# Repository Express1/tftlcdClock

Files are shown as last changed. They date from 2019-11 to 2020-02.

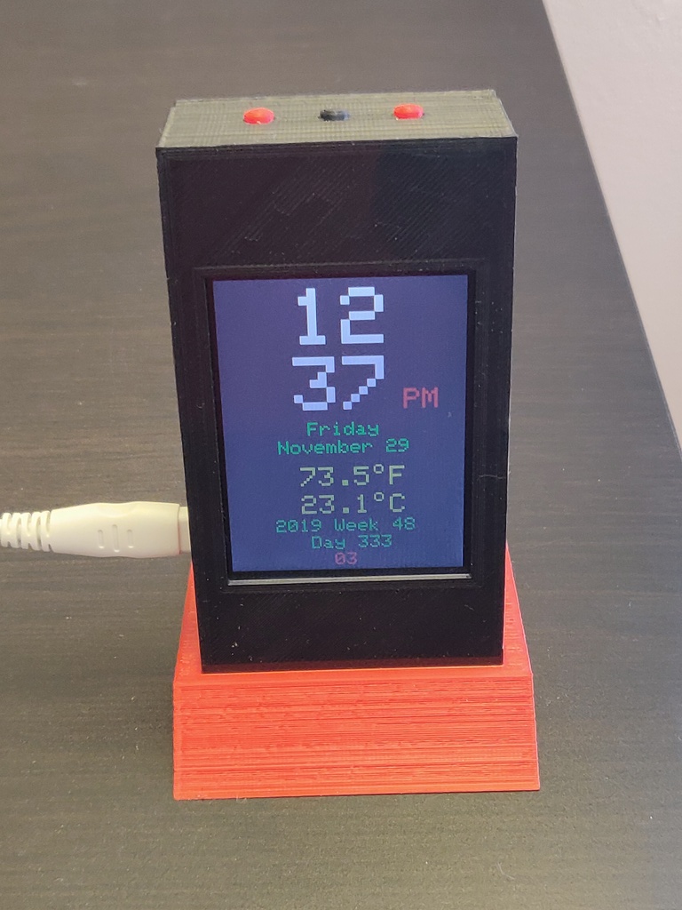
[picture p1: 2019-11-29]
pictures/IMG_20191129_123751-4.jpg

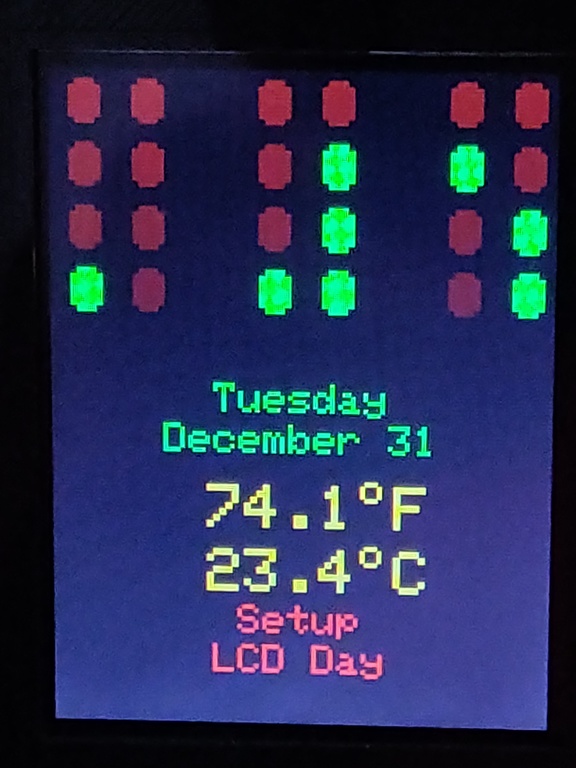
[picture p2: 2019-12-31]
pictures/IMG_20191231_102230.jpg

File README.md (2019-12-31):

TFT LCD Arduino Clock - Just another Arduino Clock...

This one is using a 320X240 ILI9341 tft lcd connected over SPI, the speed is acceptable for a clock display and will not use as many I/O pins as a parallel connected display.
Here is a link for the display:
https://www.aliexpress.com/item/32889801161.html?spm=a2g0s.9042311.0.0.29594c4dvsZfeP

The clock has a Digital display mode and a Binary BCD display mode selectabe from the menu.

Other modules used: DS3231 Clock module, remove the 1N4148 diode if you use that with a CR2032 battery, we do not want to charge the battery. DS18B20 temperature sensor module for better temp readings - there is a temperature sensor inside DS3231 also but the chip will heat up inside the clock case once powered on and will show about 1-2C more than the actual temp in few minutes.

The LCD I/O is 3v3 and therefore we use some resistors to convert from 5V to 3v3. There are 3 buttons for setup and a speaker for alarm. A piezo  or electromagnetic buzzer can be used.

The clock has an enclosure and a stand designed in OpenSCAD, make one using your 3DPrinter.

The menu of this clock is designed around a struct in PROGMEM in order to use less RAM, for those interested this can be reused as a menu for other projects. It was an interesting exercise to create and is working quite nice with the three buttons: "-", "Setup" and "+". Can be easily extended as necessary.

Menu:
Time hour, min (setting min will also reset seconds to 00), month, date, day of week, year.
Clock 12/24h, clock mode - digital or BCD binary.
Alarm hour, min, alarm days - daily or workdays only.
DST on week, month, DST off week, mo - For US DST set to 2,3 - 1,11. The week is the number of week in a mo starting Mo. The time will adjust on Su 2AM.
LCD day, night - lcd backlight durring day and night, will turn on on 7 and turn off at 10 pm.

All the libraries used are in a zip file (unzip under your libraries folder), the font file form Adafruit_GFX is modified “ char is replaced by a full circle character used by the BCD clock display and the second half of the table is removed in order to save space.

IOAbstraction lib is used to provide the low level functions for buttons and event scheduler, many thanks to Dave!
https://www.thecoderscorner.com/products/arduino-libraries/io-abstraction/ioabstraction-pins-io-expanders-shiftreg/

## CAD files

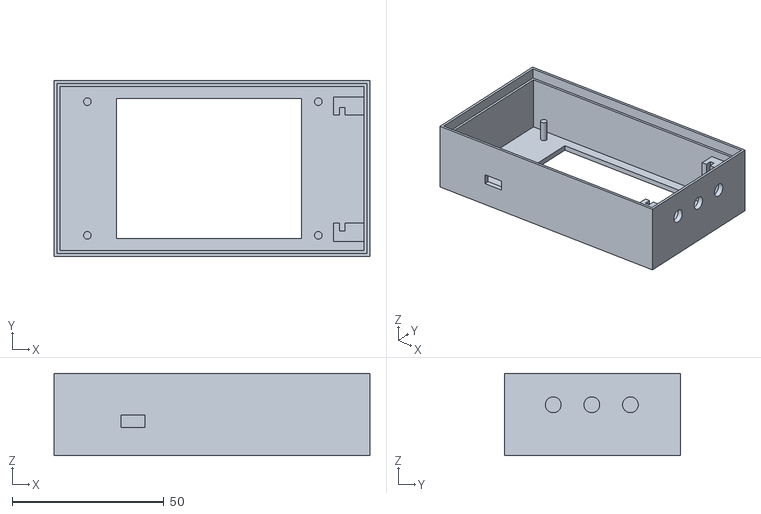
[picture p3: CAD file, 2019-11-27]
enclosure/boxLCD2p8.stl
104.0 x 58.0 x 27.0

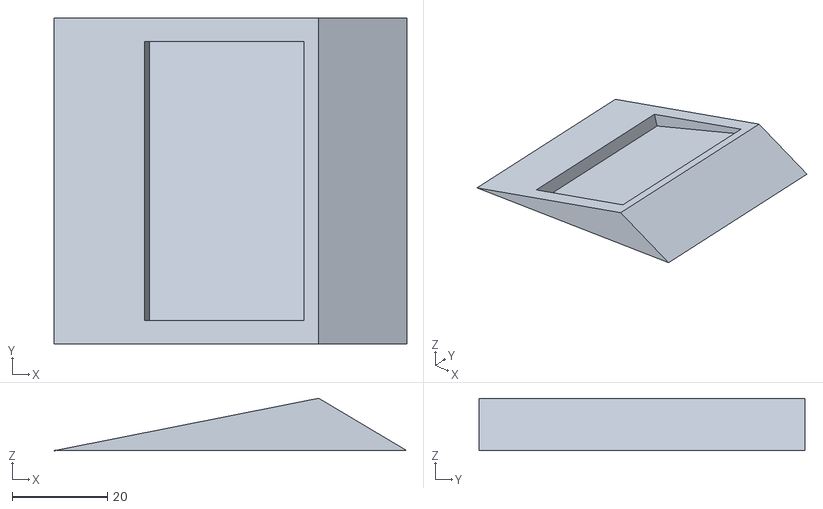
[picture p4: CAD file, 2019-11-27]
enclosure/box2p8support15.stl
74.0 x 68.4 x 11.0

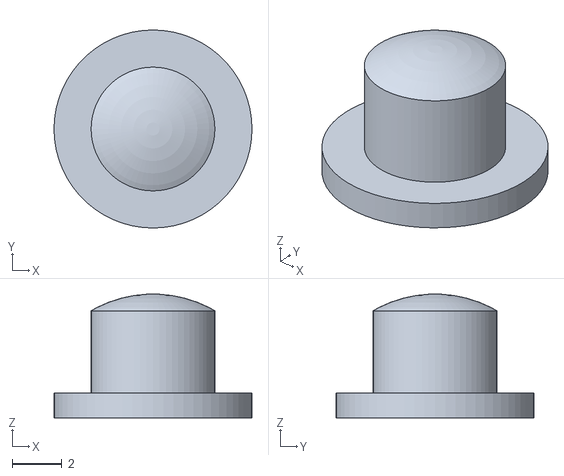
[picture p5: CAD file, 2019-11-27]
enclosure/button_clock.stl
8.00 x 8.00 x 4.99

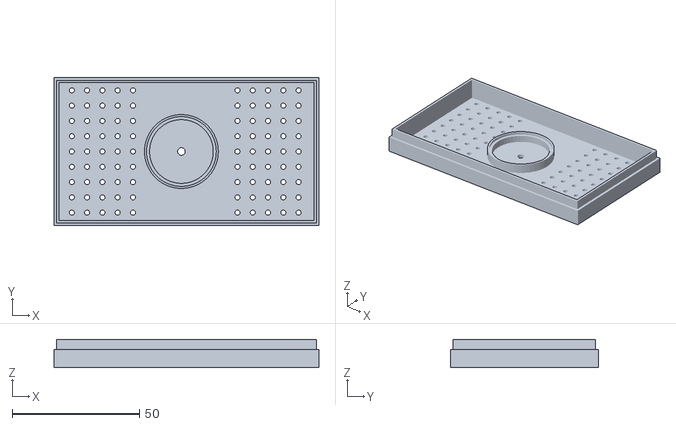
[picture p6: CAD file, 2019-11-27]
enclosure/backboxLCD2p8.stl
104.0 x 58.0 x 11.0

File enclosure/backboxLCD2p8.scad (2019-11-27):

// tftlcdClock back cover
$fn = $preview ? 12 : 72;

// inside size
wid1 = 54;
len1= 90+10;
height = 10;
wall = 2;
gap = 0.05;
cornerRadius = 10;

//buttons
 s=2.54;
 g=0.2;
 sy=11;  




//top

translate([0 , 0, 0]){
    mirror([0,0,0]) {
        //roundedBox(wid1, len1, 1, cornerRadius);
       difference() {
            roundedBox(wid1+2*wall, len1+2*wall, height/2+wall, cornerRadius);
            union() {
            translate([wall,wall,wall]) roundedBox(wid1, len1, height/2, cornerRadius);
            // holes 
            for (a2 =[0:4]) for (a1 =[1:9]) translate([wall+5+a2*6,a1*6-1,0]) cylinder(wall,d=2);
            for (a2 =[0:4]) for (a1 =[1:9]) translate([wall+70+a2*6,a1*6-1,0]) cylinder(wall,d=2);
            // buzzer    
            translate([50,29,0]) cylinder(wall,d=3);
            }
    }
    // 1 mm thick, 4 mm high
    // gap so we can close the box easy
    
    translate([wall-1,wall-1,height/2+wall]) {    
    difference() {
            roundedBox(wid1+2-gap,len1+2-gap,4,cornerRadius);
            translate([1,1,0]) {
                roundedBox(wid1,len1,4,cornerRadius);
            }    
        }
    }
  }

//buzzer

    difference() {
        translate([50,29,wall]) cylinder(r=27/2+1,h=4,center=false);
        union() {
            translate([50,29,wall])cylinder(r=27/2-1,h=4,center=false);
            translate([50,29,wall+3])cylinder(r=27/2+0.2,h=1,center=false);
            }    
        }

}



module roundedBox(wid1, len1, height, radius)
{
    dRadius = 2*radius;
    cube(size=[len1,wid1, height]);
  
}

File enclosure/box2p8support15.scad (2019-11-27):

//lcd 2.8 box top
$fn = $preview ? 12 : 72;
w=68.4;
l=74;
h=11;

difference() {
polyhedron( points = [ [0,0,0], [l,0,0], [l,w,0], [0,w,0], [l*3/4,0,h], [l*3/4,w,h]], faces =[[0,1,2,3], [0,4,1], [0,3,5,4], [4,5,2,1], [3,2,5] ], convexity = 2);

#translate([20, 5, 0]) rotate(a=[0,-15,0]) cube([34,58.4,10],false);
}

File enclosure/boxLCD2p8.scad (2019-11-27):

//lcd 2.8 box top
$fn = $preview ? 12 : 72;
//
// inside size
wid1 = 54;
len1= 90+10;
height = 50;
wall = 2;
gap = 0.05;
cornerRadius = 10;

//buttons
 s=2.54;
 g=0.2;
 sy=11;  


//bottom
difference() {
    translate([0, 0, 0]) roundedBox(wid1+2*wall, len1+2*wall, height/2+wall,cornerRadius);
    union() { 
        translate([wall,wall,wall]) roundedBox(wid1, len1, height/2, cornerRadius); 
        translate([wall-1,wall-1,height/2+wall-4-gap]) roundedBox(wid1+2,len1+2,4+gap,cornerRadius);
        //lcd hole
        translate([17+2+wall-0.5,4+wall,0]) cube(size=[61,46,wall]);
        //cuts for buttons    
        translate([len1+wall,sy,wall]) 
            union()
                for (a =[0:2])  
                {
                 #translate([0,0+a*s*5+2*s,wall+12.7]) rotate([0,90,0]) cylinder(d=5.2,h=wall);
                 *translate([0,0+a*s*5,0]) cube(size=[wall,g,6*s]); 
                 *translate([0,4*s+a*s*5,0]) cube(size=[wall,g,6*s]);
                 *translate([0,+a*s*5,6*s]) cube(size=[wall,4*s+g,g]);  
                }
         //buzzer hole
         *translate ([50,wall,23]) rotate(a=[90,0,0]) cylinder(r=1.5,h=2,center=false);  
         // USB hole
         #translate ([18+2+wall,wall,7.3+wall]) rotate(a=[90,0,0]) cube(size=[8,4,wall]);      
        }
    } 



//LCD feet
 translate([9+wall,5+wall,wall]) {
    cylinder(8,d=2.5);
        }
translate([85+wall,5+wall,wall]) {
    cylinder(8,d=2.5);
        }
        translate([9+wall,49+wall,wall]) {
    cylinder(8,d=2.5);
        }
        translate([85+wall,49+wall,wall]) {
    cylinder(8,d=2.5);
        }

// button rails
     
    difference() {
    translate([wall+len1-10,sy-6,wall]) cube(size=[10,6,8*s]);
    translate([wall+len1-10+2,sy-s,wall]) cube(size=[1.8,s,8*s]);
                 }    
         
    difference() {
    translate([wall+len1-10,sy+3*5*s-s,wall]) cube(size=[10,6,8*s]);
    translate([wall+len1-10+2,sy+3*5*s-s,wall]) cube(size=[1.8,s,8*s]);
    }


//buzzer
    *translate ([50,4,23])
    rotate(a=[90,0,0]) {
    difference() {
        cylinder(r=27/2+1,h=2,center=false);
        union() {
            cylinder(r=27/2,h=2,center=false);
            cylinder(r=27/2+0.1,h=0.5,center=false);
            } 
    }
}  




module roundedBox(wid1, len1, height, radius)
{
    dRadius = 2*radius;
    cube(size=[len1,wid1, height]);
  
}

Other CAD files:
enclosure/button_clock.scad

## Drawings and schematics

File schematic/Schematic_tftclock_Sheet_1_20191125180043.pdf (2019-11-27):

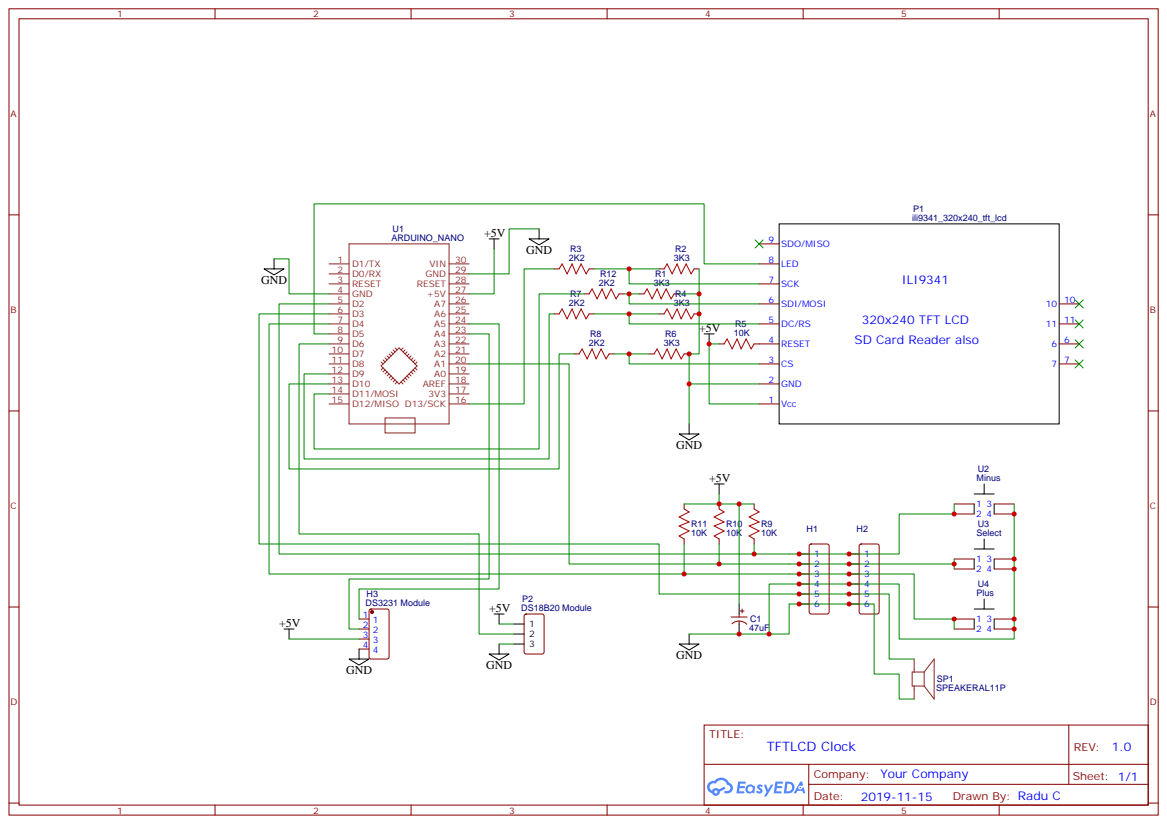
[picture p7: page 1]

320x240 TFT LCD
SD Card Reader also

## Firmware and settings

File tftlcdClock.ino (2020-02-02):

/*
   tft lcd Clock Arduino Clock

   Copyright 2019 Radu Constantinescu
   https://github.com/Express1/tftlcdClock

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
   You should have received a copy of the GNU General Public License
   along with this program; if not, write to the Free Software
   Foundation, Inc., 51 Franklin Street, Fifth Floor, Boston,
   MA 02110-1301, USA.
*/

//11/1/2020 fix DOW and DST

//Libraries
//#include <avr/pgmspace.h>
#include<IoAbstraction.h>
#include <EepromAbstraction.h>
#include <ArduinoEEPROMAbstraction.h>

#include "Adafruit_GFX.h"
#include "Adafruit_ILI9341.h"
#include <Wire.h>
#include "Sodaq_DS3231.h"
#include  <SPI.h>

//DS18B20 temp sensor
#include <OneWire.h>
#include <DS18B20.h>

#define ONE_WIRE_BUS 6

OneWire oneWire(ONE_WIRE_BUS);
DS18B20 sensor(&oneWire);
//

#define TFT_DC 9
#define TFT_CS 10
#define TFT_RST 8
#define TFT_MISO 12
#define TFT_MOSI 11
#define TFT_CLK 13

#define PINTFTLED 5
#define PINSPK 3

// used to change the LCD backlight, military time
#define STARTDAY 7
#define STARTNIGHT 22

// buttons
const int menubutton = A1;
const int minusbutton = 2;
const int plusbutton = 4;

//print info to serial
#define debug_s

char buffer[32];  //buffer
char ast[10];  //a string
uint8_t seconds; // seconds from timer chip
uint8_t minutes, hours, hours1; // last min value

uint8_t alarmon, alarmcount; //used durring alarm

uint8_t mode; // 0 = clock, 1 = BCD, 2 = setup
uint8_t menui; //menuitem

AvrEeprom anEeprom;
DateTime now;


//Adafruit_ILI9341 tft = Adafruit_ILI9341(TFT_CS, TFT_DC, TFT_MOSI, TFT_CLK, TFT_RST, TFT_MISO);
//https://forum.developer.sony.com/topic/59/hardware-spi-not-working-for-ili9340-9341-tft-display-sw-spi-does/5
// Use hardware SPI (on Uno, #13, #12, #11) and the above for CS/DC
Adafruit_ILI9341 tft = Adafruit_ILI9341(TFT_CS, TFT_DC); //HARDWARE SPI, fast
//Adafruit_ILI9341 tft = Adafruit_ILI9341(10, 9, 11, 13, 8); //SOFTWARE SPI, slow


// we define all the strings in PROGMEM

// max# of char in the array+1
const int CHARCOUNT = 10;

/*Su=1 Mo=2 Tu=3 We=4 Th=5 Fr=6 Sa=7 */
const char dayofweek [7] [CHARCOUNT] PROGMEM = {
  { "Sunday" },
  { "Monday" },
  { "Tuesday" },
  { "Wednesday" },
  { "Thursday" },
  { "Friday" },
  { "Saturday" },
};

const char months [12] [CHARCOUNT] PROGMEM = {
  { "January" },
  { "February" },
  { "March" },
  { "April" },
  { "May" },
  { "June" },
  { "July" },
  { "August" },
  { "September" },
  { "October" },
  { "November" },
  { "December" }
};

const char h1224 [2] [CHARCOUNT] PROGMEM = {
  { "24 hour" },
  { "12 hour" }
};

const char clmode [2] [CHARCOUNT] PROGMEM = {
  { "Digi Clk" },
  { "BCD Clk" }
};

const char cls[15] PROGMEM = "              ";
const char alm[5 + 1] PROGMEM = "ALARM";

const char apm [2] [2 + 1] PROGMEM = {
  { "AM" },
  { "PM" }
};

const char wday [2] [6 + 1] PROGMEM = {
  { " Week " },
  { " Day " }
};

const char alarmdays1 [3] [CHARCOUNT] PROGMEM = {
  { "AlarmOff" },
  { "Alarm On" },
  { "Workdays" }
};
const int MENUCOUNT = 18;
uint8_t menuval[MENUCOUNT];   // values for menu items

// menu callback routines

// set time
void settime1 (void) {
  DateTime now = rtc.now(); // keep seconds
  //int year = menuval[5] + 2000;
  //Serial.print(F("YYY"));
  //Serial.println(year);
  DateTime dt((menuval[5] + 2000), menuval[2], menuval[3], menuval[0], menuval[1], now.second(), menuval[4]);
  // Year, Month, Day, Hour, Minutes, Seconds, Day of Week
  rtc.setDateTime(dt); //Adjust date-time as defined 'dt' above
  mode = 3; //go back to setup
  //Serial.println (F("Routine 1"));
}

void settimemin (void) {
  DateTime now = rtc.now(); // reset seconds 
  DateTime dt((menuval[5] + 2000), menuval[2], menuval[3], menuval[0], menuval[1], 0, menuval[4]);
  // Year, Month, Day, Hour, Minutes, Seconds, Day of Week
  rtc.setDateTime(dt); //Adjust date-time as defined 'dt' above
  mode = 3; //go back to setup
}



void exitmenu2 (void) {
  mode = 3; //go back to setup
  // write an array to the rom.
  //anEeprom.writeArrayToRom(0, (const unsigned char*)menuval, sizeof menuval);
  //Serial.println (F("Routine 2"));
}

void setexit3 (void) {
  tft.fillRect(0, 0, 240, 140, ILI9341_BLACK);
  clearrow(260, 2);
  clearrow(280, 2);
  seconds--;
  minutes--; // force update sec,min, hour
  hours--;
  mode = menuval[7]; // exit menu, go back to clock
  // write an array to the rom.
  anEeprom.writeArrayToRom(0, (const unsigned char*)menuval, sizeof menuval);
  myclock();
  //Serial.println (F("Routine 3"));
}

void setlcd (void) {
  analogWrite(PINTFTLED, menuval[15]);
  mode = 3; //go back to setup
}

void setlcdn (void) {
  analogWrite(PINTFTLED, menuval[16]);
  mode = 3; //go back to setup
}
// if you want to understand how this does work read
// https://arduino.stackexchange.com/questions/13545/using-progmem-to-store-array-of-structs

struct MenuRecord
{
  uint8_t start;  // start at 0 or 1 or
  uint8_t count;  // how many, last is start+count-1
  char item[12 + 1]; // menu choice text to display
  char (*values)[CHARCOUNT];
  void (*set)();  // setup routine, call if we press set for an item
};

const MenuRecord menu[MENUCOUNT] PROGMEM = {
  { 0, 23, "Time hour", NULL , settime1 }
  , { 0, 59, "Time min", NULL , settimemin }
  , { 1, 12, "Month", months , settime1 }
  , { 1, 31, "Date", NULL, settime1 }
  , { 1, 7, "Day of week", dayofweek, settime1 }
  , { 19, 199, "Year", NULL, settime1 }
  , { 0, 1, "Clock 12/24H", h1224, setexit3 }
  , { 0, 1, "Clock mode", clmode, setexit3 }
  , { 0, 23, "Alarm hour", NULL, exitmenu2 }
  , { 0, 59, "Alarm min", NULL, exitmenu2 }
  , { 0, 2, "Alarm Days", alarmdays1 , exitmenu2 }
  , { 0, 5, "DSTonWeek", NULL , exitmenu2 }
  , { 0, 12, "DSTonMo", NULL , exitmenu2 }
  , { 0, 5, "DSToffWeek", NULL , exitmenu2 }
  , { 0, 12, "DSToffMo", NULL , exitmenu2 }
  , { 10, 255, "LCD Day", NULL , setlcd }
  , { 10, 255, "LCD Night", NULL , setlcdn }
  , { 0, 1, "Exit Setup", NULL, setexit3 }
};


/*
  menuval[0] hour 0-23
  menuval[1] min 0 -59
  menuval[2] month 1-12
  menuval[3] dayofmonth 1-31
  menuval[4] dayofweek 1-7, 1=Monday
  menuval[5] year last 2 digits 19XX
  menuval[6] 0=24h, 1=12h
  menuval[7] 0=digi, 1=bcd
  menuval[8] alarm hour
  menuval[9] alarm min
  menuval[10] alarm days 0=off, 1=on, 2=workdays
  menuval[11] DST on Week
  menuval[12] DST on Mo
  menuval[13] DST off Week
  menuval[14] DST off Mo
  menuval[15] LCD Light Day
  menuval[16] LCD Light Night
*/


void clearrow(int y, int textsize)
{
  //strcpy(buffer, "                ");
  memcpy_P (&buffer, &cls, 15);
  tftcprint(ILI9341_RED, y, textsize);
}

void onmenubutton(uint8_t pin, bool heldDown) {
  if (alarmon == 1) { //alarm stop
    alarmon = 0;
    noTone(PINSPK);
    // clear screen, print year info
    memcpy_P (&buffer, &alm, 6);
    tftcprint(ILI9341_BLACK, 260, 4);
    pyear();
  }
  else
  {
    if (!heldDown) {
      MenuRecord thisItem;
      switch (mode) {
        case 0 :
        case 1 :
          {
            mode = 3;  //setup mode
            menui = 0;
            clearrow(260, 2);
            strcpy(buffer, "Setup");
            tftcprint(ILI9341_RED, 260, 2);
            clearrow(280, 2);
            clearrow(300, 2);
            PROGMEM_readAnything (&menu [menui], thisItem);
            strcpy(buffer, thisItem.item);
            tftcprint(ILI9341_RED, 280, 2);
          }
          break;
        case 3 :
          { //show value to change
            if (menui == MENUCOUNT - 1) { //exit menu selection
              setexit3();
            }
            else {
              PROGMEM_readAnything (&menu [menui], thisItem);
              mode = 4; // the menu is selected to change values
              // show value on screen
              if (thisItem.values == NULL) {
                itoa (menuval[menui], buffer, 10);
              }
              else {
                //read day of week from menu record *
                memcpy_P (&buffer, &thisItem.values[menuval[menui] - thisItem.start], CHARCOUNT);
              }
              tftcprint(ILI9341_RED, 300, 2);
            }
          }
          break;
        case 4 :
          { //write value and go back to menu
            PROGMEM_readAnything (&menu [menui], thisItem);
            // now write the values and go back to mode 3
            thisItem.set();
            //mode = 3;
            //fix screen, delete line @ 300
            clearrow(300, 2);
            //tftcprint(ILI9341_RED, 300, 2);
          }
          break;
      }
    }
    //Serial.print(F("Button menu "));
    //Serial.println(heldDown ? F("Held") : F("Pressed"));
    //Serial.println(mode);
  }
}


// pin values
//const int minusbutton = 2;
//const int plusbutton = 4;
void onminusbutton(uint8_t pin, bool heldDown) {
  MenuRecord thisItem;
  PROGMEM_readAnything (&menu [menui], thisItem);

  switch (mode) {
    case 3 :
      {
        if (pin == minusbutton) {
          menui--;
          if (menui == 255) menui = MENUCOUNT - 1;
        }
        if (pin == plusbutton) {
          menui++;
          if (menui == MENUCOUNT) menui = 0;
        }

        clearrow(280, 2);
        PROGMEM_readAnything (&menu [menui], thisItem);
        strcpy(buffer, thisItem.item);
        tftcprint(ILI9341_RED, 280, 2);
      }
      break;
    case 4 :
      {
        if (pin == minusbutton) {
          if (menuval[menui] == thisItem.start)
          {
            menuval[menui] = thisItem.count;
          }
          else
          {
            menuval[menui]--;
          }
        }

        if (pin == plusbutton) {
          if (menuval[menui] == thisItem.count)
          {
            menuval[menui] = thisItem.start;
          }
          else
          {
            menuval[menui]++;
          }
        }

        clearrow(300, 2);
        if (thisItem.values == NULL) {
          itoa (menuval[menui], buffer, 10);
        }
        else {
          //read day of week from menu record *
          memcpy_P (&buffer, &thisItem.values[menuval[menui] - thisItem.start], CHARCOUNT);
        }
        tftcprint(ILI9341_RED, 300, 2);
      }
      break;
  }

  //Serial.println(pin);
  //Serial.println(menui);
  //Serial.print(F("Button minus "));
  //Serial.println(heldDown ? F("Held") : F("Pressed"));
}




void setup ()
{
  Wire.begin();
  rtc.begin();

  //DS18B20 tempp sensor
  sensor.begin();
  sensor.requestTemperatures();

  tft.begin();
  tft.setRotation(0);
  tft.fillScreen(ILI9341_BLACK);

  //lcd backlight
  pinMode(PINTFTLED, OUTPUT);
  

  //speaker
  pinMode(PINSPK, OUTPUT);
  tone(PINSPK, 1000, 100);

#ifdef debug_s
  Serial.begin (115200);
  Serial.println (F(">"));
#endif
  // read settings from EEPROM
  anEeprom.readIntoMemArray((const unsigned char*)menuval + 6, 0 + 6, sizeof menuval - 6); //skip rtc values 0-5

  // fix the values we read if the eeprom is empty
  for (int i = 0; i < sizeof menuval; i++) {
    //Serial.println (menuval[i]);
    if (menuval[i] == 255) menuval[i] = 0; // if we did read 255 from eeprom zero the parameter.
  }
  // fix Month and date if eeprom was empty, first start
  if (menuval[2] == 0) menuval[2] = 1; // Month Jan
  if (menuval[3] == 0) menuval[3] = 1; // Date 1

  // LCD Backlight
  if (menuval[15] < 10) menuval[15] = 10;  //otherwise we cannot see the display
  if (menuval[16] < 10) menuval[16] = 10;  
  analogWrite(PINTFTLED, menuval[15]);  // we start the clock durring day
  
  //setRTCTime();
  
  // read RTC values from clock chip
  now = rtc.now();
  menuval[0] = now.hour();
  menuval[1] = now.minute();
  menuval[2] = now.month();
  menuval[3] = now.date();
  menuval[4] = now.dayOfWeek();
  menuval[5] = uint8_t(now.year() - 2000);

  // hours, AM/PM correction
  hours1 = menuval[0];
  if (hours1 > 12) hours1 = hours1 - menuval[6] * 12;
  if (hours1 < 1) hours1 = hours1 + menuval[6] * 12;

  mode = menuval[7];  //set mode 0 = digi, 1 = bcd

  /*
    for (int i = 0; i < 12; i++)
    {
      // make a copy of the current one
      memcpy_P (&buffer, &months[i], CHARCOUNT);
      Serial.println (buffer);
    } // end of for loop

    memcpy_P (&buffer, &months[2], CHARCOUNT);
    for (int i = 0; i < 32; i++)
    {
      byte x = buffer[i];
      Serial.print(x);
      Serial.print(F(" "));
    }

    // string concat with int example
    int aaa = 30;
    char ast[10];
    itoa (aaa, ast, 10);
    strcat(buffer, " ");
    strcat(buffer, ast);
    Serial.println(F(""));
    Serial.println (buffer);
    Serial.println (strlen(buffer));

    // Menu array in PROGMEM
    MenuRecord thisItem;
    PROGMEM_readAnything (&menu [4], thisItem);
    Serial.println (thisItem.item);
    Serial.println (thisItem.count);
    //thisItem.set();
    //read day of week from menu record *
    memcpy_P (&buffer, &thisItem.values[4], CHARCOUNT);
    Serial.println (buffer);
  */

  //iobuttons
  // First we set up the switches library, giving it the task manager and tell it to use arduino pins
  // We could also of chosen IO through an i2c device that supports interrupts.
  // If you want to use PULL DOWN instead of PULL UP logic, change the true to false below.
  // true = button connected to ground
  switches.initialise(ioUsingArduino(), true);

  // now we add the switches, we dont want the spinwheel button to repeat, so leave off the last parameter
  // which is the repeat interval (millis / 20 basically) Repeat button does repeat as we can see.
  //switches.addSwitch(spinwheelClickPin, onSpinwheelClicked);
  //switches.addSwitch(repeatButtonPin, onRepeatButtonClicked, 25);

  switches.addSwitch(menubutton, onmenubutton);
  switches.addSwitch(minusbutton, onminusbutton, 25);
  switches.addSwitch(plusbutton, onminusbutton, 25);


  // run the clock display
  taskManager.scheduleFixedRate(990, myclock);  //once per second+sync

}

// end of setup

void loop () {
  taskManager.runLoop();
}

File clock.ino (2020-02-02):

/*
  // Color definitions
  #define ILI9341_BLACK       0x0000  ///<   0,   0,   0
  #define ILI9341_NAVY        0x000F  ///<   0,   0, 123
  #define ILI9341_DARKGREEN   0x03E0  ///<   0, 125,   0
  #define ILI9341_DARKCYAN    0x03EF  ///<   0, 125, 123
  #define ILI9341_MAROON      0x7800  ///< 123,   0,   0
  #define ILI9341_PURPLE      0x780F  ///< 123,   0, 123
  #define ILI9341_OLIVE       0x7BE0  ///< 123, 125,   0
  #define ILI9341_LIGHTGREY   0xC618  ///< 198, 195, 198
  #define ILI9341_DARKGREY    0x7BEF  ///< 123, 125, 123
  #define ILI9341_BLUE        0x001F  ///<   0,   0, 255
  #define ILI9341_GREEN       0x07E0  ///<   0, 255,   0
  #define ILI9341_CYAN        0x07FF  ///<   0, 255, 255
  #define ILI9341_RED         0xF800  ///< 255,   0,   0
  #define ILI9341_MAGENTA     0xF81F  ///< 255,   0, 255
  #define ILI9341_YELLOW      0xFFE0  ///< 255, 255,   0
  #define ILI9341_WHITE       0xFFFF  ///< 255, 255, 255
  #define ILI9341_ORANGE      0xFD20  ///< 255, 165,   0
  #define ILI9341_GREENYELLOW 0xAFE5  ///< 173, 255,  41
  #define ILI9341_PINK        0xFC18  ///< 255, 130, 198
*/

/*
  void setRTCTime()
  {
  DateTime dt(2019, 11, 11, 17, 21, 00, 0); // Year, Month, Day, Hour, Minutes, Seconds, Day of Week
  rtc.setDateTime(dt); //Adjust date-time as defined 'dt' above
  }
*/

void tftcprint(uint16_t color, int y, int textSize)
// print buffer[] center justified on tft
{
  int x;
  //chard are 5X7 with one px space, 6 px width.
  x = (240 - strlen(buffer) * 6 * textSize) / 2;
  //if (x < 0) {
  //  x = 0;
  //};
  /*
    Serial.print (F("center x:"));
    Serial.print (x);
    Serial.print (F(" strlen:"));
    Serial.println (strlen(buffer));
      for (int i = 0; i < 16; i++)
    {
      byte x = buffer[i];
      Serial.print((buffer[i]));
      Serial.print(x);
      Serial.print(F(" "));

    }
    Serial.println("");
  */
  tftprint(color, x, y, textSize);
}


void tftprint(uint16_t color, int x, int y, int textSize)
// print buffer[] on tft, will delete previous text
// https://github.com/adafruit/Adafruit-GFX-Library/issues/16 , have print clear existing text
//To prevent having to clear the text before its drawn,
//like AKA mentions try using the bg color by calling setTextColor(foreground color, background color)
{
  //Serial.println (buffer);
  tft.setCursor(x, y);
  tft.setTextColor(color, ILI9341_BLACK);
  tft.setTextSize(textSize);
  tft.setTextWrap(true);
  tft.print(buffer);

}


void ptemp()
{

  // RTC temp sensor
  rtc.convertTemperature();
  float temperaturec = rtc.getTemperature();
  Serial.print(sensor.getTempC());
  Serial.print(F(" "));
  //

  // DS18B20 temp sensor
  //float
  temperaturec = sensor.getTempC() - 0.5;
  //Serial.println(sensor.getTempC());
  sensor.requestTemperatures();

  //

  float temperaturef;
  temperaturef = (temperaturec * 1.8) + 32;

  dtostrf(temperaturef, 5, 1, buffer);
  strcat(buffer, " F");
  tftcprint(ILI9341_YELLOW, 200, 3);
  strcpy(buffer, "o");
  tftprint(ILI9341_YELLOW, 149, 194, 2);

  dtostrf(temperaturec, 5, 1, buffer);
  strcat(buffer, " C");
  tftcprint(ILI9341_YELLOW, 200 + 8 * 4, 3);
  strcpy(buffer, "o");
  tftprint(ILI9341_YELLOW, 149, 194 + 8 * 4, 2);

#ifdef debug_s
  Serial.print(temperaturec); //read registers and display the temperature
  Serial.print(F(" C / "));
  Serial.print(temperaturef); //read registers and display the temperature
  Serial.println(F(" F"));
#endif
}

// BCD display parameters
#define S 3 //char size 20/2 or 30/3
#define P 30 //spacing

#define C ILI9341_GREEN //color on
#define O ILI9341_MAROON //color off

#define X 10 //X offset
#define Y 5 //Y offset

void bcdp(uint8_t val, uint8_t x )
{
  for (int i = 0; i < 4; i++) {
    if (val & (0b1000 >> i)) {
      strcpy(buffer, "\""); tftprint(C, x * P + X, P * i + Y, S);
    }
    else {
      strcpy(buffer, "\""); tftprint(O, x * P + X, P * i + Y, S);
    }
  }
}


void pyear()
//DayWeekNumber: Calculate day of year and week of year
// this routine does come from http://arduino.joergeli.de
/*
  menuval[0] hour 0-23
  menuval[1] min 0 -59
  menuval[2] month 1-12
  menuval[3] dayofmonth 1-31
  menuval[4] dayofweek 0-6, 0=Monday
  menuval[5] year last 2 digits 19XX
*/
{
  int days[] = {0, 31, 59, 90, 120, 151, 181, 212, 243, 273, 304, 334};
  int DN, WN;
  // Number of days at the beginning of the month in a not leap year.
  //Start to calculate the number of day
  if (menuval[2] == 1 || menuval[2] == 2) {
    DN = days[(menuval[2] - 1)] + menuval[3]; //for any type of year, it calculate the number of days for January or february
  }                                                          // Now, try to calculate for the other months
  else if (((menuval[5] + 2000) % 4 == 0 && (menuval[5] + 2000) % 100 != 0) ||  (menuval[5] + 2000) % 400 == 0) { //those are the conditions to have a leap year
    DN = days[(menuval[2] - 1)] + menuval[3] + 1;                              // if leap year, calculate in the same way but increasing one day
  }
  else {                                                     //if not a leap year, calculate in the normal way, such as January or Febr
    DN = days[(menuval[2] - 1)] + menuval[3];
  }
  // Now start to calculate Week number
  if (menuval[4] == 0) {
    WN = (DN - 7 + 10) / 7;                                  //if it is sunday (time library returns 0)
  }
  else {
    WN = (DN - menuval[4] + 10) / 7;                                  // for the other days of week
  }

  itoa ((menuval[5] + 2000), buffer, 10);
  memcpy_P (&ast, wday[0], 7);
  strcat(buffer, ast);
  itoa (WN, ast, 10);
  strcat(buffer, ast);
  tftcprint(ILI9341_GREEN, 260, 2);
  memcpy_P (&buffer, wday[1], 7);
  //strcpy(buffer, " Day ");
  itoa (DN, ast, 10);
  strcat(buffer, ast);
  tftcprint(ILI9341_GREEN, 280, 2);
}


void doalarm()
{
  // if (alarmon == 0) {
  alarmon = 1;
  alarmcount = 60;
  //memcpy_P (&buffer, &alm, 6);
  //tftcprint(ILI9341_RED, 260, 4);
  doalarm1();
  // }
#ifdef debug_s
  Serial.println (F("Alarm"));
#endif

}

void doalarm1()
{
  if (alarmon == 1 && alarmcount > 0) {
    taskManager.scheduleOnce(1000, doalarm1);
    tone(PINSPK, 1000, 600);

    memcpy_P (&buffer, &alm, 6);
    if (alarmcount % 2 == 0) {
      tftcprint(ILI9341_RED, 260, 5);
    }
    else {
      tftcprint(ILI9341_BLACK, 260, 5);
    }

    alarmcount--;
#ifdef debug_s
    //Serial.println(alarmcount);
    //Serial.println(millis());
#endif
  }
  else {
    alarmon = 0;
    memcpy_P (&buffer, &alm, 6);
    tftcprint(ILI9341_BLACK, 260, 5);
    pyear();
    //setexit3();
  }
}


void pdate()
{
  //cleanup
  clearrow(150, 2);
  //get day of week string
  memcpy_P (&buffer, &dayofweek[menuval[4] - 1], CHARCOUNT);
  tftcprint(ILI9341_GREEN, 150, 2);
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

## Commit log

2019-11-29 Add pictures and fix startupp.
    [clock.ino, tftlcdClock.ino]
2020-02-02 fix DOW and DST
    [clock.ino, tftlcdClock.ino]

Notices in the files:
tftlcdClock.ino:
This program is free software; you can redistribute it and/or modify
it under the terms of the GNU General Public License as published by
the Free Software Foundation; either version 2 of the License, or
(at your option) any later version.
